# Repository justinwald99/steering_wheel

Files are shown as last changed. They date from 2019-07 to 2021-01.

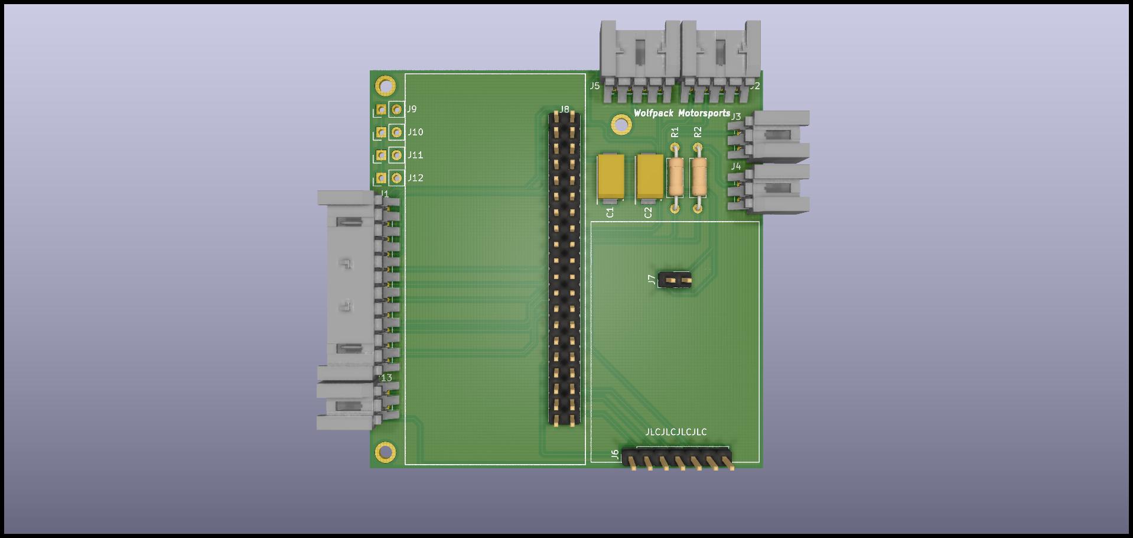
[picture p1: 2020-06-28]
Hardware/SteeringWheelKicad.jpg

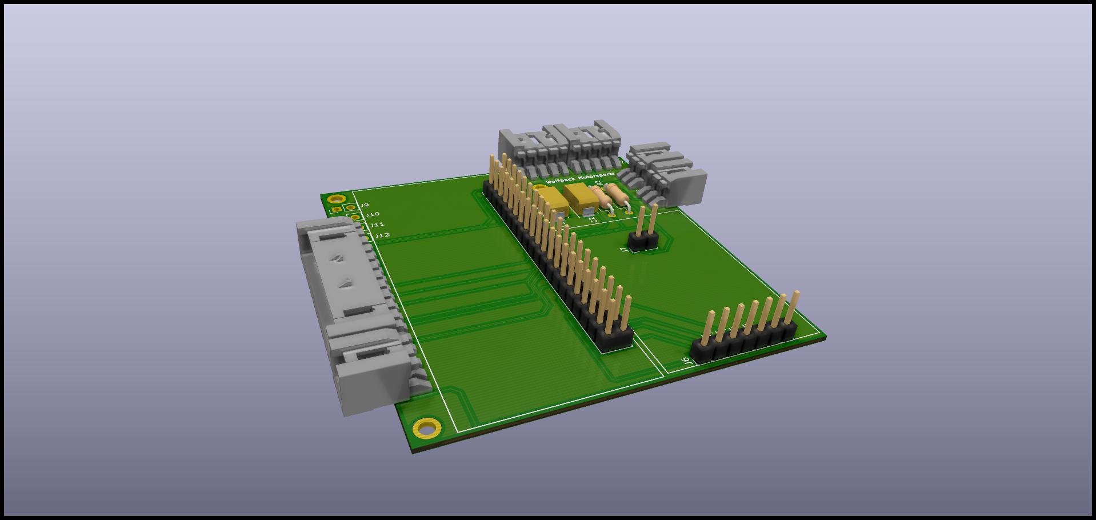
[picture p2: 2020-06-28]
Hardware/SteeringWheelKicad1.jpg

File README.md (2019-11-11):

# Steering-Wheel

## Setup

The CAN board used by the steering wheel needs to be setup before it can be used in the Python code for the wheel.

**Step 1:** &nbsp;Add the CAN device to the /boot/config.txt folder on the Pi. To do this, run vim (not installed by default) on the config.txt file with sudo by running the following command:  

    sudo vim /boot/config.txt
and add the following lines:  

    dtoverlay=spi1-3cs
    dtoverlay=mcp2515-can1-1,oscillator=16000000,interrupt=12
The line `dtoverlay=spi1-3cs` tells the raspberry Pi to enable the second spi bus, which is spi1.0, spi1.1, and spi1.2 (the .0, .1, and .2 indicate which chip select a device is using and is allowed reffered to as CS or CE). We need to use the second spi bus because the first one (spi0.0 and spi0.1) is being used by the screen.  
The next line, `dtoverlay=mcp2515-can1-1,oscillator=16000000,interrupt=12` is where we register our CAN chip. This is done by loading the `mcp2515-can1-1` overlay and passing it parameters for the oscillator and interrupt. This overlay will have to be downloaded from this repo (in the Pi `Overlays/Compiled` folder) because the default linux overlays for the MCP2515 only work for spi 0.0 and 0.1. Typically, the 1-1 version should be used, which is written for spi1.1 (CS on BCM pin 17), but I've also created and compiled overlays for 1.0 and 1.2 in case those pins are more convenient. The parameters should be pretty simple, the oscillator is the frequency of the crystal oscillator hooked to the mcp2515 and the interrupt is the pin wired to the interrupt of the MCP2515.  
If done correctly, an entry named **can0** should appear when running the `ifconfig -a` command.

**Step 2:**&nbsp; Automatically start the can network on system start. You can manually start the can0 network with the `sudo ip link set can0 up type can bitrate 1000000` command. Ideally, however, we want this network to be created on startup. This is achieved by adding the following code to the `/etc/network/interfaces` file:

    auto can0
    iface can0 inet manual
        pre-up ip link set $IFACE type can bitrate 1000000 listen-only off restart-ms 1
        up /sbin/ifconfig $IFACE up
        down /sbin/ifconfig $IFACE down
If successful, the command `candump can0` shouldn't produce an error and should provide a stream of can messages being received by the board.  
**Step 3:**&nbsp; Setup the screen. To do this, paste the following commands into the Pi's terminal:

    cd ~
    wget https://raw.githubusercontent.com/adafruit/Raspberry-Pi-Installer-Scripts/master/adafruit-pitft.sh
    chmod +x adafruit-pitft.sh
    sudo ./adafruit-pitft.sh
This will run Adafruit's automated setup procedure. Fill out the options for the 3.5in resistive screen and rotate it 90 degrees. Then answer "no" to the question `Would you like the console to appear on the PiTFT display` and yes to the question `Would you like the HDMI display to mirror to the PiTFT display?`. For more information about this process follow the guide at  https://learn.adafruit.com/adafruit-pitft-3-dot-5-touch-screen-for-raspberry-pi/easy-install-2.

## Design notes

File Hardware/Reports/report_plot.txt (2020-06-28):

Plot file “C:\Users\mchld\Documents\NCSU\WolfPack Motorsports\KiCad\SteeringWheelAttempt2\SteeringWheelKicad\SteeringWheel_v3_Gerb\SteeringWheelKicad-F_Cu.gbr” created.
Plot file “C:\Users\mchld\Documents\NCSU\WolfPack Motorsports\KiCad\SteeringWheelAttempt2\SteeringWheelKicad\SteeringWheel_v3_Gerb\SteeringWheelKicad-B_Cu.gbr” created.
Plot file “C:\Users\mchld\Documents\NCSU\WolfPack Motorsports\KiCad\SteeringWheelAttempt2\SteeringWheelKicad\SteeringWheel_v3_Gerb\SteeringWheelKicad-F_Paste.gbr” created.
Plot file “C:\Users\mchld\Documents\NCSU\WolfPack Motorsports\KiCad\SteeringWheelAttempt2\SteeringWheelKicad\SteeringWheel_v3_Gerb\SteeringWheelKicad-B_Paste.gbr” created.
Plot file “C:\Users\mchld\Documents\NCSU\WolfPack Motorsports\KiCad\SteeringWheelAttempt2\SteeringWheelKicad\SteeringWheel_v3_Gerb\SteeringWheelKicad-F_SilkS.gbr” created.
Plot file “C:\Users\mchld\Documents\NCSU\WolfPack Motorsports\KiCad\SteeringWheelAttempt2\SteeringWheelKicad\SteeringWheel_v3_Gerb\SteeringWheelKicad-B_SilkS.gbr” created.
Plot file “C:\Users\mchld\Documents\NCSU\WolfPack Motorsports\KiCad\SteeringWheelAttempt2\SteeringWheelKicad\SteeringWheel_v3_Gerb\SteeringWheelKicad-F_Mask.gbr” created.
Plot file “C:\Users\mchld\Documents\NCSU\WolfPack Motorsports\KiCad\SteeringWheelAttempt2\SteeringWheelKicad\SteeringWheel_v3_Gerb\SteeringWheelKicad-B_Mask.gbr” created.
Plot file “C:\Users\mchld\Documents\NCSU\WolfPack Motorsports\KiCad\SteeringWheelAttempt2\SteeringWheelKicad\SteeringWheel_v3_Gerb\SteeringWheelKicad-Edge_Cuts.gbr” created.

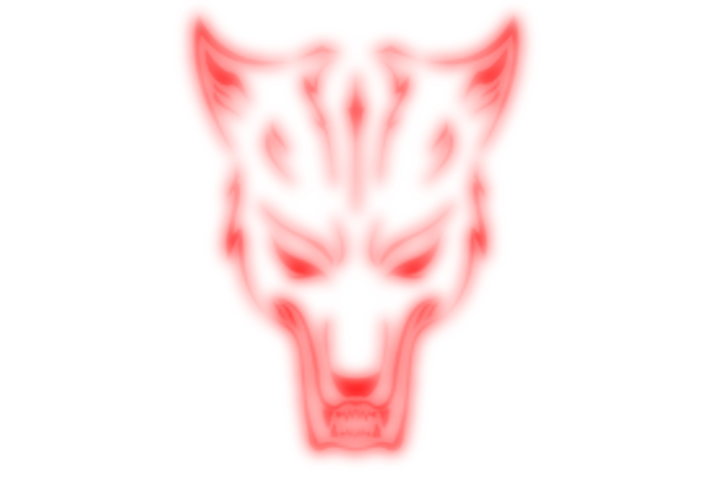
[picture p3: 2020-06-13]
assets/wmf_wolf.png

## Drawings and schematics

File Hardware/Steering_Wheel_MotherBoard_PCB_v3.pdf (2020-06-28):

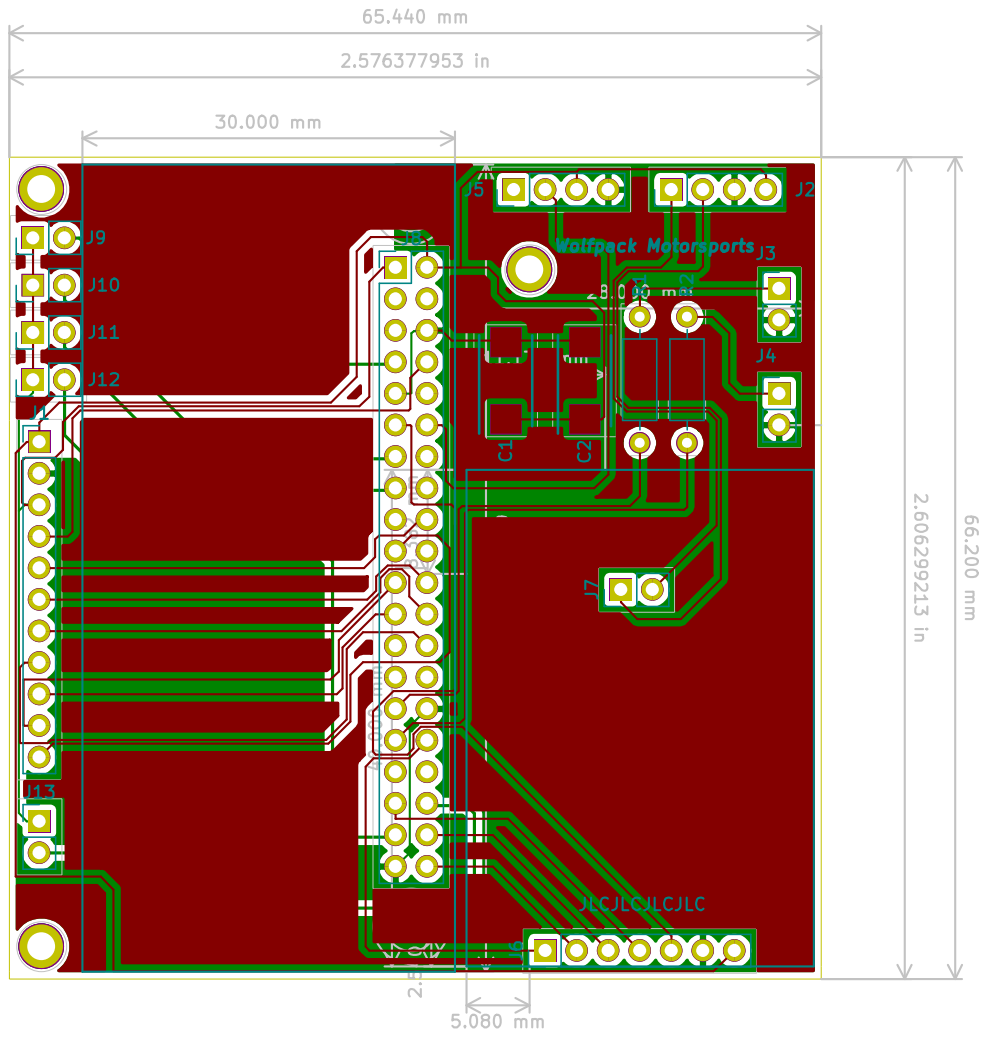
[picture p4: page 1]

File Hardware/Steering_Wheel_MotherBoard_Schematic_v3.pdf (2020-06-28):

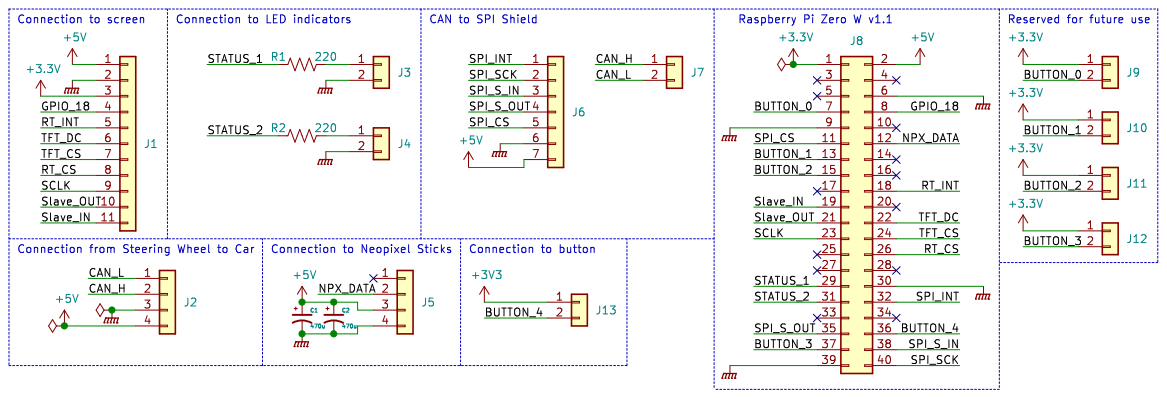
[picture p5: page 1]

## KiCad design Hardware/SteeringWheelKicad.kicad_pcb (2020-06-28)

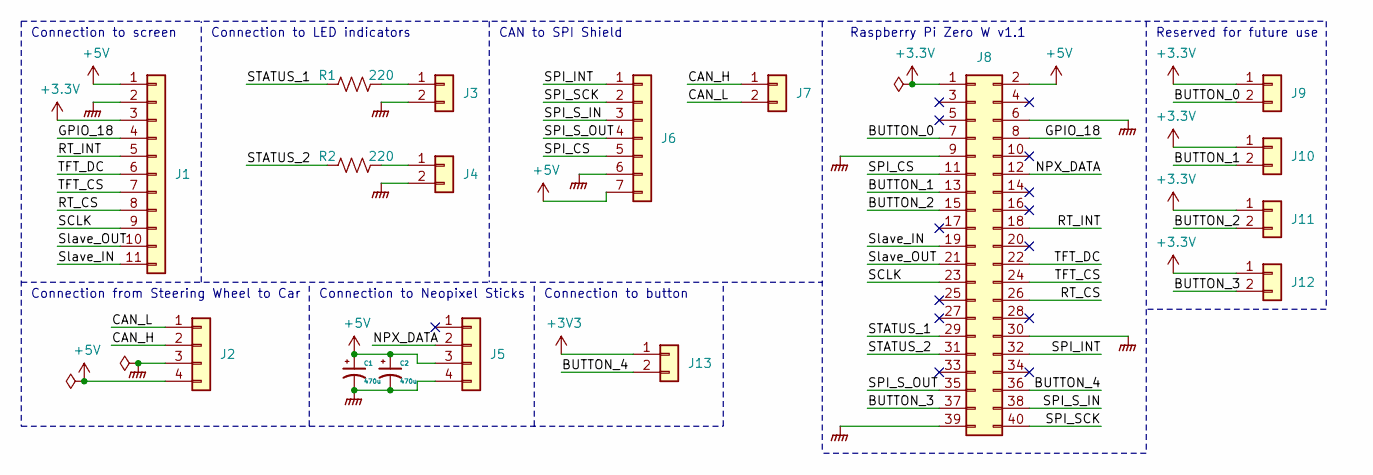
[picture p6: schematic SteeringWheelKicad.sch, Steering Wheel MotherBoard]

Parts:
C1, C2: 470u; CAPPM7343X310N
J1: Conn_01x11; PinHeader_1x11_P2.54mm_Vertical
J2, J5: Conn_01x04; PinHeader_1x04_P2.54mm_Vertical
J3, J4, J7, J9, J10, J11, J12, J13: Conn_01x02; PinHeader_1x02_P2.54mm_Vertical
J6: Conn_01x07; PinHeader_1x07_P2.54mm_Vertical
J8: Conn_02x20_Odd_Even; PinHeader_2x20_P2.54mm_Vertical
R1, R2: 220; R_Axial_DIN0207_L6.3mm_D2.5mm_P10.16mm_Horizontal

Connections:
+5V: C1.1, C2.1, J1.1, J2.4, J5.3, J6.7, J8.2
/BUTTON_0: J8.7, J9.2
/BUTTON_1: J8.13, J10.2
/BUTTON_2: J8.15, J11.2
/BUTTON_3: J8.37, J12.2
/BUTTON_4: J8.36, J13.2
/CAN_H: J2.2, J7.1
/CAN_L: J2.1, J7.2
/GPIO_18: J1.4, J8.8
/NPX_DATA: J5.2, J8.12
/RT_CS: J1.8, J8.26
/RT_INT: J1.5, J8.18
/SCLK: J1.9, J8.23
/SPI_CS: J6.5, J8.11
/SPI_INT: J6.1, J8.32
/SPI_SCK: J6.2, J8.40
/SPI_S_IN: J6.3, J8.38
/SPI_S_OUT: J6.4, J8.35
/STATUS_1: J8.29, R1.2
/STATUS_2: J8.31, R2.2
/Slave_IN: J1.11, J8.19
/Slave_OUT: J1.10, J8.21
/TFT_CS: J1.7, J8.24
/TFT_DC: J1.6, J8.22
GNDPWR: C1.2, C2.2, J1.2, J2.3, J3.2, J4.2, J5.4, J6.6, J8.6, J8.9, J8.30, J8.39
unnamed: J3.1, R1.1
unnamed: J4.1, R2.1

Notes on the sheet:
Connection to screen
Connection to LED indicators
CAN to SPI Shield
Connection to Neopixel Sticks
Connection from Steering Wheel to Car
Connection to button
Reserved for future use
Raspberry Pi Zero W v1.1

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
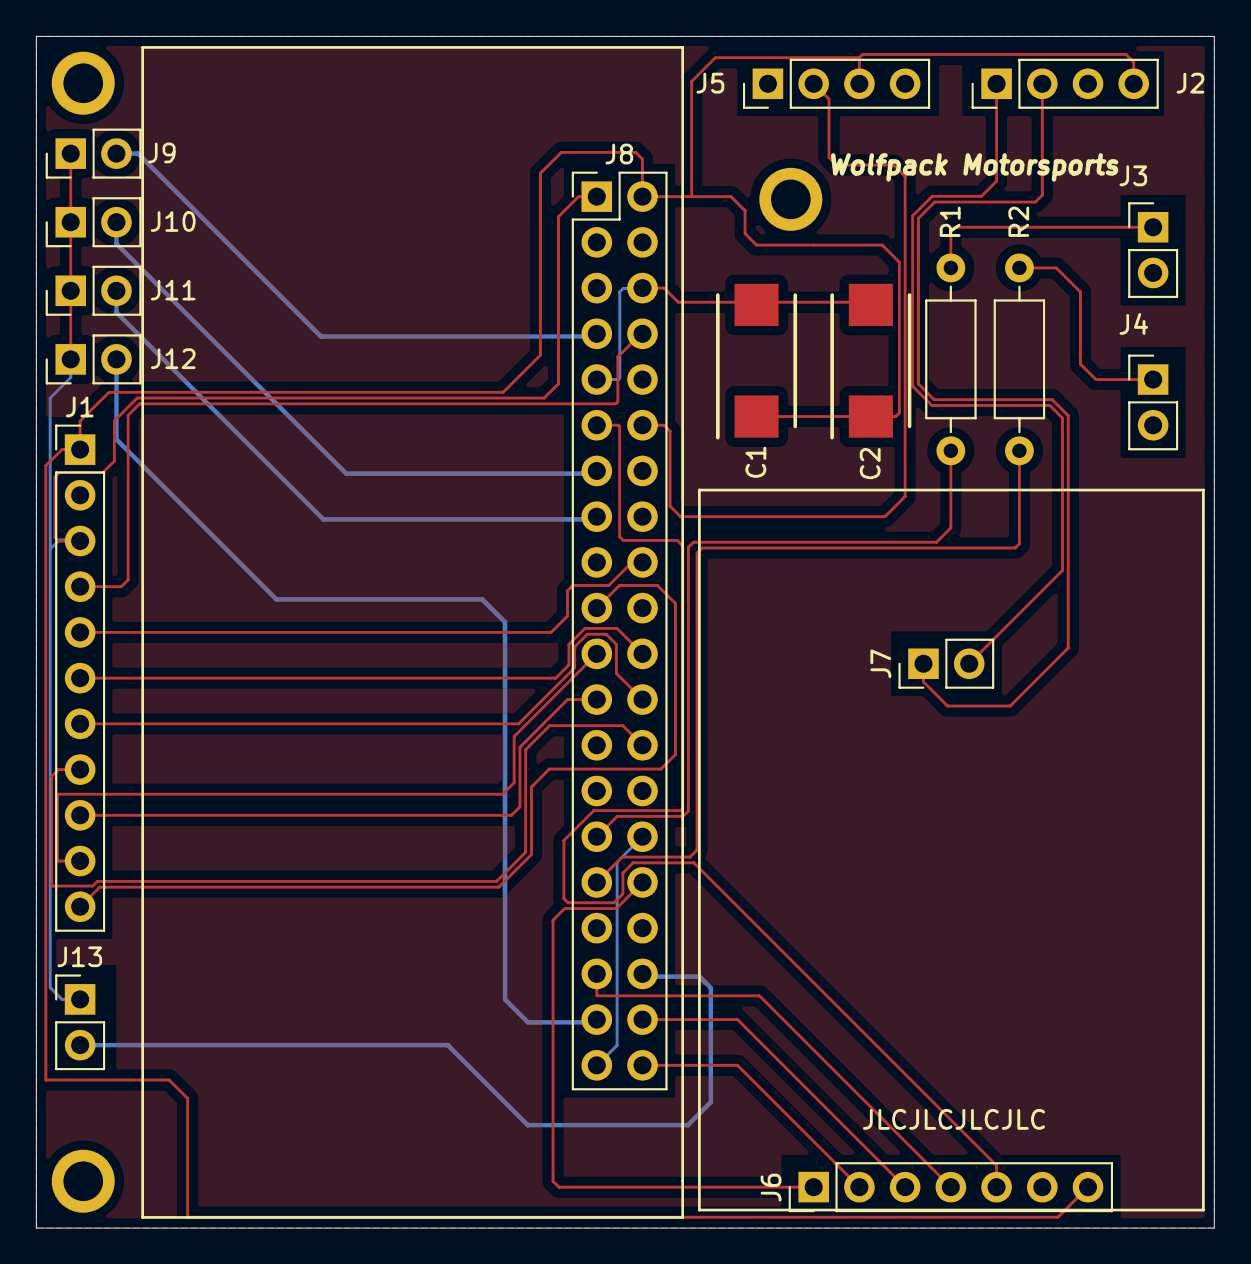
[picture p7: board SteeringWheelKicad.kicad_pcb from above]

Board: 2 copper layers, 65.4 x 66.2 mm, 20 parts (0 on the bottom side), 28 nets.

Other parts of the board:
MH1, MH2, MH3: MountingHole_2.2mm_M2_ISO7380_Pad

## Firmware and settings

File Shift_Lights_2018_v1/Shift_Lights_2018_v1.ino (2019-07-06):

// WM Racing steering wheel arduino board 2018
// use Seeed Studio CAN Bus Shield and Library

//Libraries:
#include <Adafruit_NeoPixel.h>
#include <SPI.h>
#include "mcp_can.h"

//NeoPixel Strip Pin
#define PIN 6

// CAN Address of the recieveing device:
#define CAN_ID 10

// CAN sensor channels, in the order they appear in the custom data set 2
// in MoTeC. Each channel has 2 bytes of data for compound messaging
// Message format: 0:index 1:0 2:a 3:b 4:c 5:d 6:e 7:f
//                 1:index 1:0 2:g 3:h 4:i 5:j 6:k 7:l
// Where the number is the byte number and the letter is the specific index

#define number_channels 5 //number of CAN channels being sent

// Channel set 1 
#define run_time [2 3] // channel 1 [a, b]
//#define rpm [4, 5]  // channel 2 [c, d]
#define engine_temp [6, 7]  // channel 3 [e, f]

// Channel set 2
#define oil_pressure [2, 3]  // channel 4 [g, h]
#define throttle_position [4, 5]  // channel 5 [i, j]

#define channel_layout [0, 1, 2, 3, 4, 5, 6, 7]

// To convert CAN message from HEX to measured value:
// Channel data = (256*a + b)x
// where a = first byte, b = second byte, x = scaling factor
// Scaling factor comes from MoTeC document PSAU0015
double scaling[] = {1, 1, .1, .1, .1}; // in order of the channels


//Constants:
// the cs pin of the version after v1.1 is default to D9
// v0.9b and v1.0 is default D10
const int SPI_CS_PIN = 9;

unsigned char len = 0;
unsigned char buf[8];


// Initiate NeoPixel strip
Adafruit_NeoPixel strip = Adafruit_NeoPixel(16, PIN, NEO_GRB + NEO_KHZ800);

uint32_t 
  green = strip.Color(0, 255, 0),
  yellow = strip.Color(255, 255, 0),
  red = strip.Color(255, 0, 0),
  flash1 = strip.Color(255, 255, 255),
  flash2 = strip.Color(0, 0, 255),
  color[3] = {green, yellow, red};

long prevBlinkTime = 0;

int 
  prev_range = 10,
  shiftPT[2] = {1500, 3000},  // point 0 = the activation point 1 = warning point
  ledStages[4] = {0,3,5,7},   // this is where each stage of the led strip is set. i.e. from ledStages[0] and ledStages[1] is stage one and so on
  warningState = 0,
  blinkInterval = 150,
  security_led_opt = 0,       // 0 = off, 1 = blink , 2 = knight rider
  stripBrightness = 255,      // 0 = off, 255 = fullbright
  ledFlip[] = {15, 14, 13, 12, 11, 10, 9, 8},
  chan1,
  chan2,
  chan3,
  chan4,
  chan5,
  chan6;

MCP_CAN CAN(SPI_CS_PIN);    // Set CS (chip select) pin

//Debugging
#define Serial_start 1


void setup()
{
    if(Serial_start == 1)
    {
        Serial.begin(19200);
    }
    
    while (CAN_OK != CAN.begin(CAN_1000KBPS))   // init can bus : baudrate = 1000k
    {
        Serial.println("CAN BUS Shield init fail");
        Serial.println(" Init CAN BUS Shield again");
        delay(100);
    }
    Serial.println("CAN BUS Shield init ok!");

      strip.begin();
  strip.setBrightness(stripBrightness);
  strip.show(); // Initialize all pixels to 'off'
}


void loop()
{
    unsigned char len = 0;
    unsigned char buf[8];

    if(CAN_MSGAVAIL == CAN.checkReceive())            // check if data coming
    {
        CAN.readMsgBuf(&len, buf);    // read data,  len: data length, buf: data buf

        unsigned long canId = CAN.getCanId();    // gets CAN address
        if (canId == CAN_ID) 
        {        
        //    Serial.println("-----------------------------");
         //   Serial.print("Get data from ID: 0x");
          //  Serial.println(canId, HEX);
            
            for(int i = 0; i<len; i++)    // print the data
            {
              //  Serial.print(buf[i], HEX);
              //  Serial.print("\t");
            }
            
            messageConversion(buf);
            
         //   Serial.print("\t");
         //   Serial.print(len, HEX);
         //  Serial.println();
        } 
    
     }
    
}

void messageConversion(unsigned char buf[])
{    
    if(buf[0] == 0)  // Channel set 1
    {
      int chan1 = ((buf[2])* 256 + (buf[3]))*scaling[0];
      int chan2 = ((buf[4])* 256 + (buf[5]))*scaling[1];
      int chan3 = ((buf[6])* 256 + (buf[7]))*scaling[2];
      Serial.println(chan2);
      shift_lights(chan2); 
    }
    else if(buf[0] == 1)
    {
      int chan4 = ((buf[2])* 256 + (buf[3]))*scaling[3];
      int chan5 = ((buf[4])* 256 + (buf[5]))*scaling[4];
 //     int chan6 = ((buf[6])* 256 + (buf[7]))*scaling[5];

    }   

}

void shift_lights(int rpm)
{
unsigned long currentMillis = millis();
  Serial.println(rpm);
  if (rpm >= shiftPT[0] && rpm < shiftPT[1]) { //if the RPM is between the activation pt and the shift pt
    //map the RPM values to 9(really 8 since the shift point and beyond is handled below)and constrain the range
    int rpmMapped = map(rpm, shiftPT[0], shiftPT[1], 0, 8);
    int rpmConstrained = constrain(rpmMapped, 0, 8);
    
   
    if (prev_range != rpmConstrained) { //This makes it so we only update the LED when the range changes so we don't readdress the strip every reading
      prev_range = rpmConstrained;
#ifdef USE_SERIAL      
      Serial.print("RPM LED Range: ");
      Serial.println(rpmConstrained);
      Serial.print("RPM: ");
      Serial.println(rpm);
#endif     
      clearStrip();
      for (int ledNum = 0; ledNum <= rpmConstrained; ledNum++) {
        if (ledNum <= ledStages[1]) 
        { 
          strip.setPixelColor(ledNum, color[0]);
          strip.setPixelColor(ledFlip[ledNum], color[0]); 
        }
        else if (ledNum > ledStages[1] && ledNum <= ledStages[2])
        { 
          strip.setPixelColor(ledNum, color[1]);
          strip.setPixelColor(ledFlip[ledNum], color[1]);  
        }
        else if (ledNum > ledStages[2] && ledNum < strip.numPixels()) 
        { 
          strip.setPixelColor(ledNum, color[2]);
          strip.setPixelColor(ledFlip[ledNum], color[2]);  
        }
      }
      strip.show();
    }
  }
  else if (rpm >= shiftPT[1]) { //SHIFT DAMNIT!! This blinks the LEDS back and forth with no delay to block button presses
    prev_range = 8;
    if (currentMillis - prevBlinkTime > blinkInterval){
      prevBlinkTime = currentMillis;
      
      if (warningState == 0){
        warningState = 1;
        for(int i = 0; i < strip.numPixels(); i=i+2){
          strip.setPixelColor(i, flash1);
        }
        for(int i = 1; i < strip.numPixels(); i=i+2){
          strip.setPixelColor(i, 0);
        }
      }
      else {
        warningState = 0;
        for(int i = 1; i < strip.numPixels(); i=i+2){
          strip.setPixelColor(i, flash2);
        }
        for(int i = 0; i < strip.numPixels(); i=i+2){
          strip.setPixelColor(i, 0);
        }
      }
      strip.show();
    }
  }
  else {
    if (prev_range != 10) {
      prev_range = 10;
      clearStrip();
#ifdef USE_SERIAL      
      Serial.println("Exiting strip range");
#endif      
    }
  }
}

//====================
// Clears the led strip
//====================
void clearStrip() {
  for (int ledNum = ledStages[0]; ledNum <= strip.numPixels(); ledNum++) {
    strip.setPixelColor(ledNum, 0);
  }
  strip.show(); 
}

//====================
// Blink the first led 
//====================
void blink_led(int count, int ms_delay, int colorInt) {
  clearStrip();
  strip.setBrightness(stripBrightness/4);
  for (int i = 0; i < count; i++) {
    strip.setPixelColor(0, colorInt);
    strip.show(); 
    delay(ms_delay);
    clearStrip();
    delay(ms_delay/2);
  }
  strip.setBrightness(stripBrightness);
  clearStrip();
}


/*********************************************************************************************************
  END FILE
*********************************************************************************************************/

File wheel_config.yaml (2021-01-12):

can_channels:
  - name: oil_pressure
    scaling_factor: 0.1
  - name: oil_temperature
    scaling_factor: 0.1
  - name: water_temperature
    scaling_factor: 0.1
  - name: fuel_pressure
    scaling_factor: 0.1
  - name: gear_position
    scaling_factor: 1
  - name: battery_voltage
    scaling_factor: 0.01
  - name: engine_rpm
    scaling_factor: 1

ui_elements:
  # - type: Background
  #   channel_name: engine_rpm
  #   imagePath: assets/wmf_wolf.png
  #   min_val: 11000
  #   max_val: 12500
  - type: bar_gauge
    channel_name: oil_pressure
    label: Oil P
    x_coord: 100
    y_coord: 150
    unit: PSI
    min_val: 0
    max_val: 300
  - type: bar_gauge
    channel_name: oil_temperature
    label: Oil T
    x_coord: 220
    y_coord: 150
    unit: F
    min_val: 0
    max_val: 250
  - type: bar_gauge
    channel_name: water_temperature
    label: Water T
    x_coord: 460
    y_coord: 150
    unit: F
    min_val: 0
    max_val: 220
  - type: bar_gauge
    channel_name: fuel_pressure
    label: Fuel P
    x_coord: 580
    y_coord: 150
    unit: PSI
    min_val: 0
    max_val: 500
  - type: gear_display
    channel_name: gear_position
    min_val: 1
  - type: voltage_box
    channel_name: battery_voltage
    min_val: 0
  - type: rpm_display
    threshold_val: 10000
    min_val: 0
    max_val: 12500
    channel_name: engine_rpm
  - type: driver_warning
    channel_list: [battery_voltage]
    x_coord: 15
    y_coord: 160
    conditionals: ["battery_voltage < 12"]
    image_path: assets/battery_warning.png
  - type: driver_warning
    channel_list: [oil_temperature]
    x_coord: 15
    y_coord: 240
    conditionals: ["oil_temperature > 100"]
    image_path: assets/oil_temp_warning.png
  - type: driver_warning
    channel_list: [water_temperature]
    x_coord: 641
    y_coord: 160
    conditionals: ["water_temperature > 200"]
    image_path: assets/water_temp_warning.png
  - type: driver_warning
    channel_list: [oil_pressure, engine_rpm]
    x_coord: 641
    y_coord: 240
    conditionals: ["oil_pressure > 200", "engine_rpm > 11000 critical"]
    image_path: assets/generic_warning.png
element_config:
  bar_gauge:
    bar_width: 40
    bar_height: 200
    outline_width: 5
    text_size: 24
  gear_display:
    gear_size: 256
  voltage_box:
    border_thickness: 5
    text_size: 64
  rpm_display:
    text_size: 64
    vertical_pos: 10
  driver_warning:
    text_size: 14
    text_truncate_length: 9

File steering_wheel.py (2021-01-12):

"""Main module of the steering wheel that facilitates display."""
import datetime
import logging
import os
import sys
import time

import can
import pygame
import yaml
from gpiozero import PWMLED, Button

from can_read import can_channel
from ui_utils import element_factory

# Path to the config file.
CONFIG_PATH = "config.yaml"

# Path to the config for aspects of the ui and can functionality.
WHEEL_CONFIG_PATH = "wheel_config.yaml"

# Number of log files with debug info kept at a time.
KEPT_LOGS = 25

# Check if there are more than KEPT_LOGS number of log files, delete oldest if neccesary.
while (len(os.listdir("logs")) > KEPT_LOGS - 1):
    fileList = dict()
    for logFile in os.listdir("logs"):
        fileList.update({os.path.getctime(f"logs/{logFile}"): logFile})
    sortedFiles = list(fileList.keys())
    os.remove(f"logs/{fileList[sortedFiles[0]]}")
# Create a new logfile with timestamp.
logging.basicConfig(
    filename=f"logs/steering_wheel_log_{datetime.datetime.now().strftime('%a-%b-%d-%Y--%H-%M-%S%p')}.txt",
    level="DEBUG")
wheelLogger = logging.getLogger('steering_wheel')

wheelLogger.debug("Starting log...")

# Open the config file.
with open(CONFIG_PATH, 'r') as configFile:
    try:
        config = yaml.safe_load(configFile)
        wheelLogger.debug("Config loaded...")
    except yaml.YAMLError as exc:
        wheelLogger.critical(f"Could not open config file: {exc}")
        exit(0)


class SteeringWheel(can.notifier.Notifier):
    """An instance of the steering wheel display.

    Parameters
    ----------
    bus : can.Bus
        Instance of the CAN bus used to recieve messages.

    """

    # Default background color
    BACKGROUND_COLOR = pygame.Color("white")

    def __init__(self, bus):
        """Create a new instance of the steering wheel."""
        # Initialize the display.
        pygame.init()
        self.surface = pygame.display.set_mode([config["options"]["h_res"], config["options"]["v_res"]])
        wheelLogger.debug(f"Display initialized with size: {pygame.display.get_window_size()}")
        self.isNightMode = False
        self.brightnessControl = PWMLED(config["pi_pins"]["brightness_pin"], frequency=1000)
        self.change_brightness()

        # Initialize the Notifier componoent.
        super().__init__(bus, [can_channel("Custom Data Set")])

        # Read the config.
        self.read_config()

    def read_config(self):
        """Read the config and create elements."""
        # Open the wheel config file.
        with open(WHEEL_CONFIG_PATH, 'r') as configFile:
            try:
                wheel_config = yaml.safe_load(configFile)
                wheelLogger.debug("UI config loaded...")
            except yaml.YAMLError as exc:
                wheelLogger.critical(f"Could not open config file: {exc}")
                exit(0)

        # Initialize the ui element factory.
        self.factory = element_factory(self.surface, self.read_theme(config["paths"]["default_theme_path"]),
                                       wheel_config)

        # Add CAN channels to the notifier.
        for channel in wheel_config["can_channels"]:
            self.listeners[0].add_compound_channel(channel['name'], channel['scaling_factor'])
            wheelLogger.debug(f"Channel loaded: {channel['name']}.")

        # Add each element in wheel_config.
        for element in wheel_config['ui_elements']:
            self.factory.add_element(element)

    def update(self):
        """Redraw the elements with updated values and blit the screen."""
        # Write black to the screen before every blit.
        self.surface.fill(self.factory.get_theme()['BACKGROUND_COLOR'])

        self.factory.update_all()

        # "Flip" the display (update the display with the newly created surface).
        pygame.display.flip()

    def read_theme(self, fileName):
        """Load in a new theme from a fileName and updates the reference used by all ui_elements.

        Parameters
        ----------
        fileName : string
            Path to the file that contains the theme information to use.

        """
        with open(fileName, "r") as theme:
            loaded_theme = yaml.safe_load(theme)
        # Convert the hex colors in pygame.Color objects.
        for name, color in loaded_theme.items():
            loaded_theme.update({name: pygame.Color(color)})
        return loaded_theme

    def toggle_night_mode(self):
        """Toggle nightmode on the screen."""
        if self.isNightMode:
            self.isNightMode = False
            self.factory.set_theme(config["paths"]["default_theme_path"])
        else:
            self.isNightMode = True
            self.factory.set_theme(config["paths"]["night_theme_path"])

    def change_brightness(self):
        """Change the brightness of the screen in 25% incremenets."""
        self.brightnessControl.value = (
            self.brightnessControl.value - .25) % 1.25


def setup():
    """Run on steering wheel startup."""
    # Create the CAN bus. SocketCan is the kernel support for CAN,
    # can0 is the network created with SocketCan, and the bitrate
    # of the network is 1000000 bits/s.
    canBus = can.interface.Bus(bustype='socketcan', channel='can0', bitrate=1000000)

    # Add a filter to only listen on CAN ID 10, the custom data set ID from motec.
    canBus.set_filters([{"can_id": config["can_info"]["can_channel_id"], "can_mask": 0xF, "extended": False}])

    # Create an instance of the steering wheel listener.
    global wheel
    wheel = SteeringWheel(canBus)

    # Create the right button below the screen.
    global button
    button = Button(config["pi_pins"]["br_button_pin"], pull_up=False)
    button.when_held = wheel.toggle_night_mode
    button.when_activated = wheel.change_brightness

    # Start the loop.
    screen_loop()


def screen_loop():
    """Loop to update the screen."""
    last_update_time = time.time()
    while True:
        for event in pygame.event.get():
            # Exit button.
            if event.type == pygame.QUIT:
                sys.exit()
            # Escape to stop running.
            elif event.type == pygame.KEYDOWN and event.key == pygame.K_ESCAPE:
                sys.exit()

        # Update screen at given refresh rate.
        if (time.time() - last_update_time > 1 / config["options"]["refresh_rate"]):
            wheel.update()
            wheelLogger.debug(f"frametime: {time.time() - last_update_time}")
            last_update_time = time.time()


if __name__ == '__main__':
    setup()

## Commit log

2019-11-11 Added documentation for the CAN board setup on the Pi.
2019-11-11 Reorganized files
    [Steering Wheel Board.fzz, Steering Wheel Internal Test v1.fzz]
2020-01-23 Completed voltage, gearpos, and gauges.
2020-05-12 Partial rework
    [config.csv]
2020-06-03 Began rework
    [config.csv]
2020-06-05 Working rework pre-warning
    [config.csv]
2020-06-19 Added schematics folder
2020-06-19 Added support for conditional based warnings. Added logtofile capability.
    [config.csv]
2020-06-22 removed old files
    [Steering Wheel Board.fzz, Steering Wheel Internal Test v1.fzz]
2020-06-23 Began implementation of physical button interaction.
2020-06-23 Added support for the two status LEDs.
2020-06-24 Updated screen backlight control pin.
2020-06-28 Create foo.txt
    "Changing the folder name" of schematics to Hardware to better reflect what it contains
2020-06-28 Add files via upload
    The current version of the steering wheel
    [SteeringWheelKicad.kicad_pcb, SteeringWheelKicad.sch]
2020-06-28 uploaded gerbers
    [SteeringWheelKicad-B_Cu.gbr, SteeringWheelKicad-B_Mask.gbr, SteeringWheelKicad-B_Paste.gbr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]
2020-06-28 Drill maps added
    Drill maps are not necessary normally but it is here just in case we need it
